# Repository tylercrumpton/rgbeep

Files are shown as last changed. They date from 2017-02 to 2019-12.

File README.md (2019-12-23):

# rgbeep
An ESP-powered RGB-lit jumbo button using APA102 LEDs.

pcb-toppcb-bottom

## Overview
The **RGBeep** is a large, colorful WiFi button made using the parts from an off-the-shelf "tap light".
It was inspired by [todbot's CrashSpace BigButton][todbot] that uses the same components. I loved the design,
but wanted to use APA102 RGB LEDs instead WS2182s, remove the "sacrificial Neopixel", and play with the mechanics a little bit.

On board, there are 16 APA102 SPI-controllable RGB LEDs, four pushbuttons, and a socket for either a Wemos D1 Mini ESP8266 module
or a [Synapse-powered S1 Mini][s1].

The diffuser insert is optional, but helps to hide the pixels underneath the dome. It is meant to be installed between 
the PCB and the dome with the "fins" oriented downwards, torward the PCB. White filament is recommended. 
The model was designed/printed/tested with an FDM printer at .2mm layer height.

## Operation
The **RGBeep**'s D1 Mini or S1 Mini module communicate with the APA102 LEDs via SPI, and the pushbuttons are connected to GPIO pins.
The pin mappings are as follows:

| Description | Module Pin |
|---|---|
| APA102 CLK  | D5 |
| APA102 DATA | D7 |
| Switch SW1  | D1 |
| Switch SW2  | D2 |
| Switch SW3  | D3 |
| Switch SW4  | D4 |

[pcb-top]: https://cloud.githubusercontent.com/assets/1317406/22604399/045c0e30-ea11-11e6-9dd1-bee5b901c55e.png
[pcb-bottom]: https://cloud.githubusercontent.com/assets/1317406/22604385/fb816bde-ea10-11e6-9f9d-aa37f6f3053a.png
[todbot]: https://todbot.com/blog/2017/01/12/crashspace-bigbutton-w-esp8266/
[s1]: https://github.com/tylercrumpton/s1-mini

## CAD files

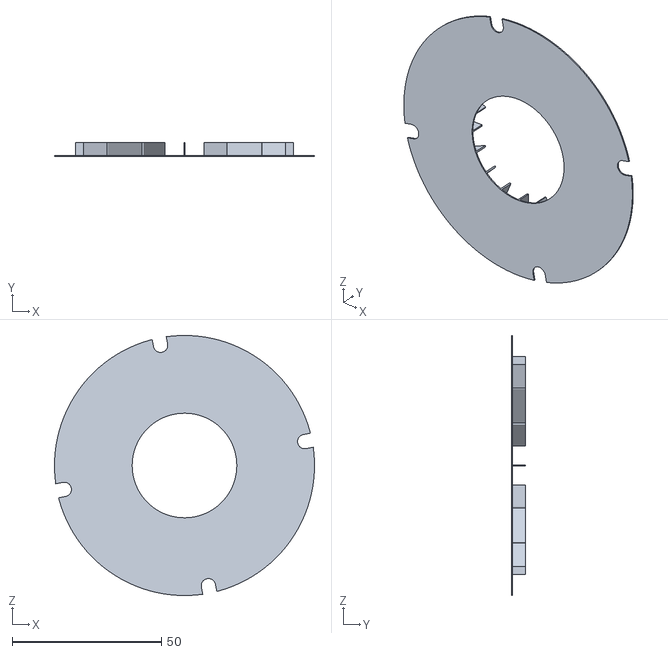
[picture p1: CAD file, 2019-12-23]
hardware/led_diffuser_insert.stl
87.0 x 4.80 x 87.0

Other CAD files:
hardware/led_diffuser_insert.f3d

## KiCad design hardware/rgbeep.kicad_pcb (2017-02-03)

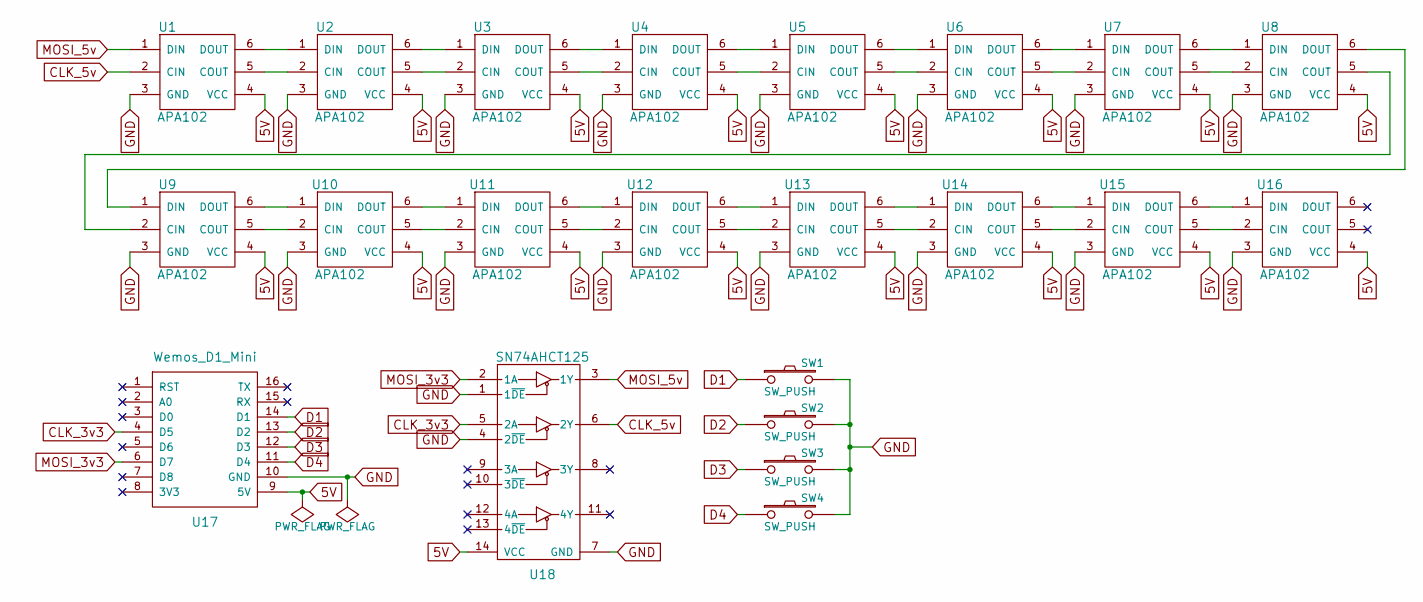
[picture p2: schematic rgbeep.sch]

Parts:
SW1, SW2, SW3, SW4: SW_PUSH; 6x6mm_pushbutton
U1, U2, U3, U4, U5, U6, U7, U8, U9, U10, U11, U12, U13, U14, U15, U16: APA102
U17: Wemos_D1_Mini; D1_mini
U18: SN74AHCT125; SOIC-14_3.9x8.7mm_Pitch1.27mm

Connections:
5V: U1.4 (VCC), U2.4 (VCC), U3.4 (VCC), U4.4 (VCC), U5.4 (VCC), U6.4 (VCC), U7.4 (VCC), U8.4 (VCC), U9.4 (VCC), U10.4 (VCC), U11.4 (VCC), U12.4 (VCC), U13.4 (VCC), U14.4 (VCC), U15.4 (VCC), U16.4 (VCC), U17.9 (5V), U18.14 (VCC)
CLK_3v3: U17.4 (D5), U18.5 (2A)
CLK_5v: U1.2 (CIN), U18.6 (2Y)
D1: SW1.1, U17.14 (D1)
D2: SW2.1, U17.13 (D2)
D3: SW3.1, U17.12 (D3)
D4: SW4.1, U17.11 (D4)
GND: SW1.2, SW2.2, SW3.2, SW4.2, U1.3 (GND), U2.3 (GND), U3.3 (GND), U4.3 (GND), U5.3 (GND), U6.3 (GND), U7.3 (GND), U8.3 (GND), U9.3 (GND), U10.3 (GND), U11.3 (GND), U12.3 (GND), U13.3 (GND), U14.3 (GND), U15.3 (GND), U16.3 (GND), U17.10 (GND), U18.1 (1~DE), U18.4 (2~DE), U18.7 (GND)
MOSI_3v3: U17.6 (D7), U18.2 (1A)
MOSI_5v: U1.1 (DIN), U18.3 (1Y)
unnamed: U1.5 (COUT), U2.2 (CIN)
unnamed: U1.6 (DOUT), U2.1 (DIN)
unnamed: U2.5 (COUT), U3.2 (CIN)
unnamed: U2.6 (DOUT), U3.1 (DIN)
unnamed: U3.5 (COUT), U4.2 (CIN)
unnamed: U3.6 (DOUT), U4.1 (DIN)
unnamed: U4.5 (COUT), U5.2 (CIN)
unnamed: U4.6 (DOUT), U5.1 (DIN)
unnamed: U5.5 (COUT), U6.2 (CIN)
unnamed: U5.6 (DOUT), U6.1 (DIN)
unnamed: U6.5 (COUT), U7.2 (CIN)
unnamed: U6.6 (DOUT), U7.1 (DIN)
unnamed: U7.5 (COUT), U8.2 (CIN)
unnamed: U7.6 (DOUT), U8.1 (DIN)
unnamed: U8.5 (COUT), U9.2 (CIN)
unnamed: U8.6 (DOUT), U9.1 (DIN)
unnamed: U9.6 (DOUT), U10.1 (DIN)
unnamed: U9.5 (COUT), U10.2 (CIN)
unnamed: U10.5 (COUT), U11.2 (CIN)
unnamed: U10.6 (DOUT), U11.1 (DIN)
unnamed: U11.5 (COUT), U12.2 (CIN)
unnamed: U11.6 (DOUT), U12.1 (DIN)
unnamed: U12.5 (COUT), U13.2 (CIN)
unnamed: U12.6 (DOUT), U13.1 (DIN)
unnamed: U13.5 (COUT), U14.2 (CIN)
unnamed: U13.6 (DOUT), U14.1 (DIN)
unnamed: U14.5 (COUT), U15.2 (CIN)
unnamed: U14.6 (DOUT), U15.1 (DIN)
unnamed: U15.5 (COUT), U16.2 (CIN)
unnamed: U15.6 (DOUT), U16.1 (DIN)

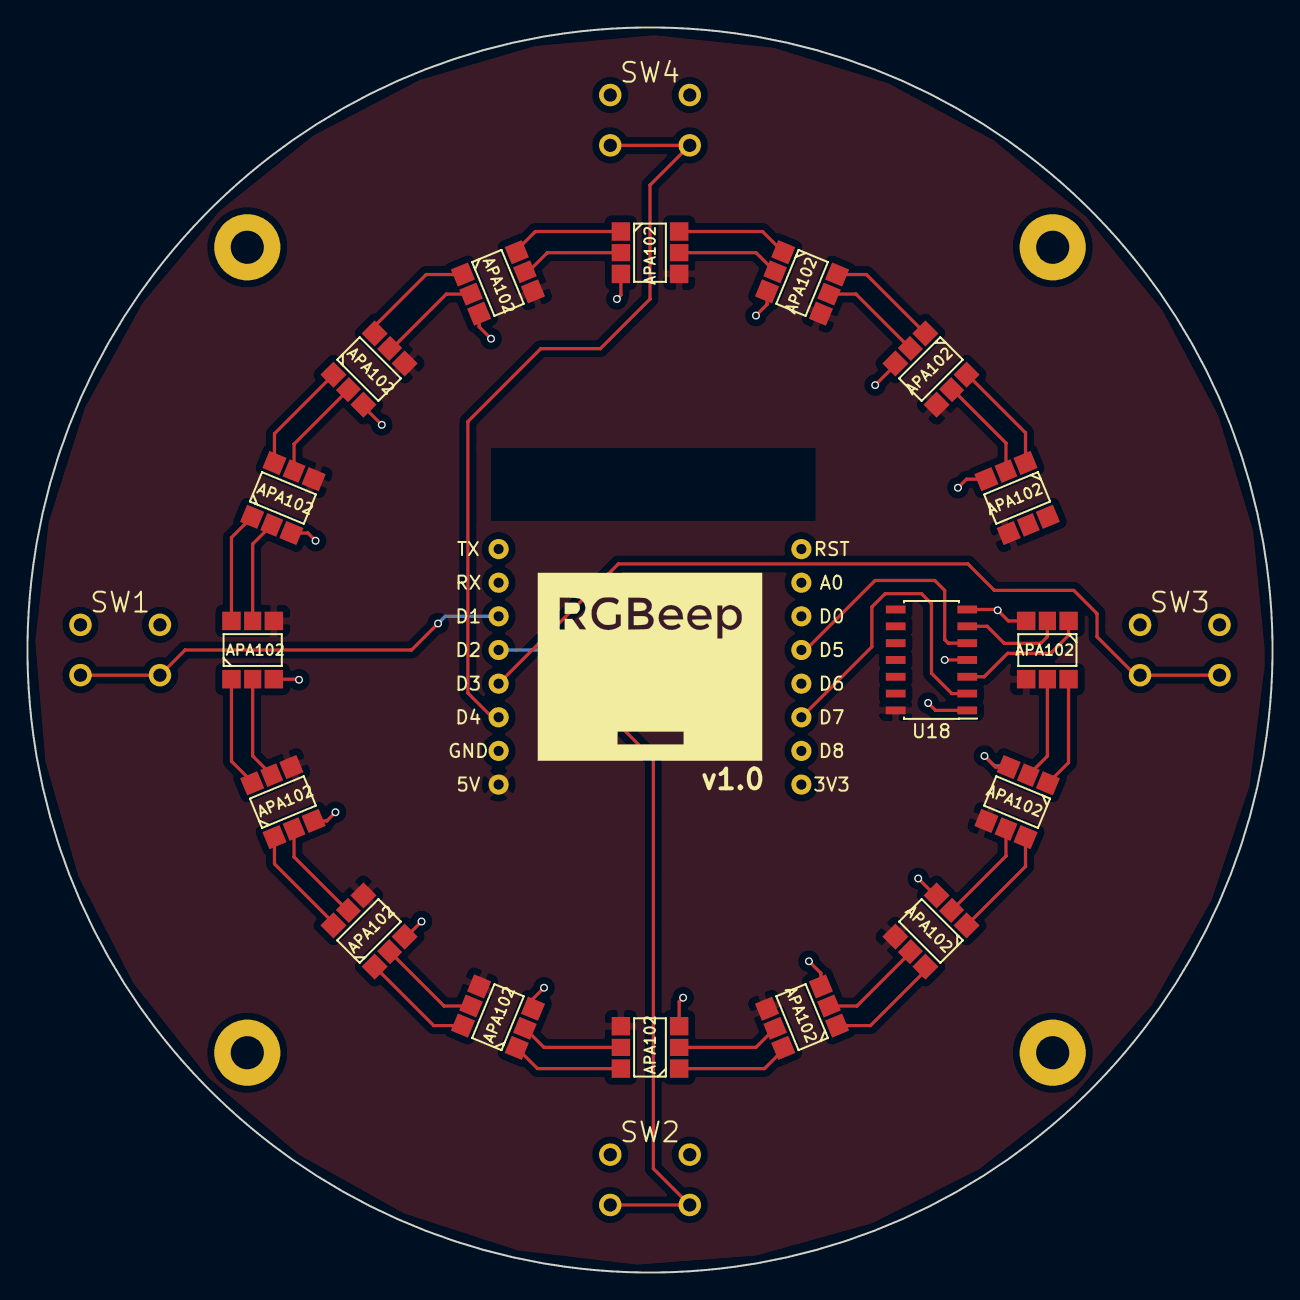
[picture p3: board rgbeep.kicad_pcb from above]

Board: 2 copper layers, 94.0 x 94.0 mm, 22 parts (1 on the bottom side), 40 nets.

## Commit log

2017-01-29 Add KiCad project template.
    [rgbeep.kicad_pcb, rgbeep.sch]
2017-01-29 Add schematic capture.
    [rgbeep.sch]
2017-01-29 Select footprints for parts.
    [rgbeep.sch]
2017-02-01 Route v1.0 board.
    [rgbeep.kicad_pcb]
2017-02-03 Set plot settings.
    [rgbeep.kicad_pcb]
2017-03-02 Fix DATA pin number.
2019-12-22 3D printable LED diffuser insert f3d and stl files plus README notes
    [led_diffuser_insert.f3d, led_diffuser_insert.stl]

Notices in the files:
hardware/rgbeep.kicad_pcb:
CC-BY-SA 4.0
